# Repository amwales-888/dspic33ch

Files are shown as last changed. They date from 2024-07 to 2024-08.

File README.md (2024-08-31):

# dspic33ch

Simple development board for 3.3v 80pin TQFP dspic33ch.

- 3.3v LDO powered from 5V USB.
- UART connectivity to USB via ch340 optionally connected using jumpers B1-B2.
- programming interface header.
- With exception of CLKI (B0) and MCLR all other pins are broken out to headers.
- 2 LEDS optionally connected to pins A0-A1 using jumpers.
- 2 Buttons optionally connected to pins A2-A3 using jumpers.

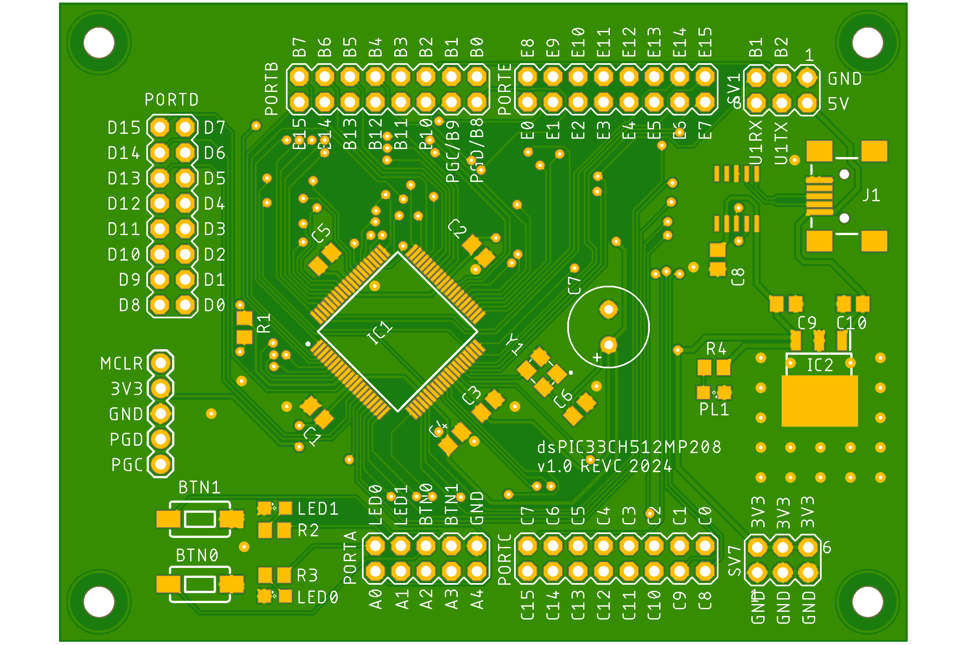
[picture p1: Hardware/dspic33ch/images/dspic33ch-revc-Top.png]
Board Top

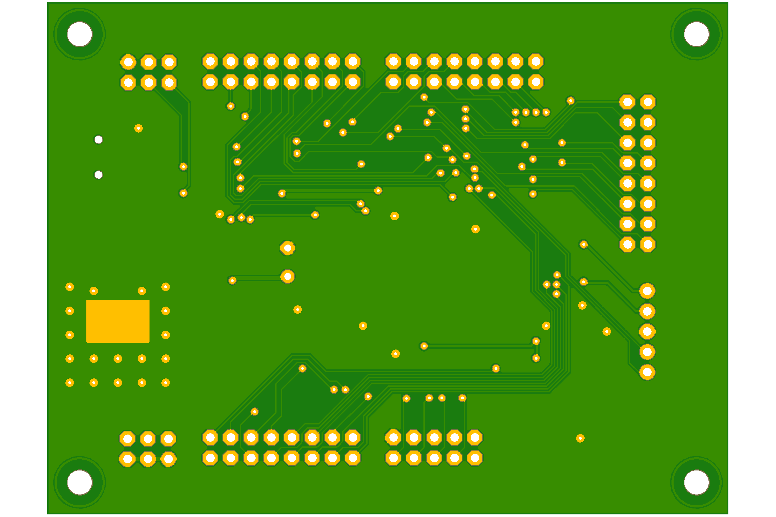
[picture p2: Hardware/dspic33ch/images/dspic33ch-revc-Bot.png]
Board Bottom


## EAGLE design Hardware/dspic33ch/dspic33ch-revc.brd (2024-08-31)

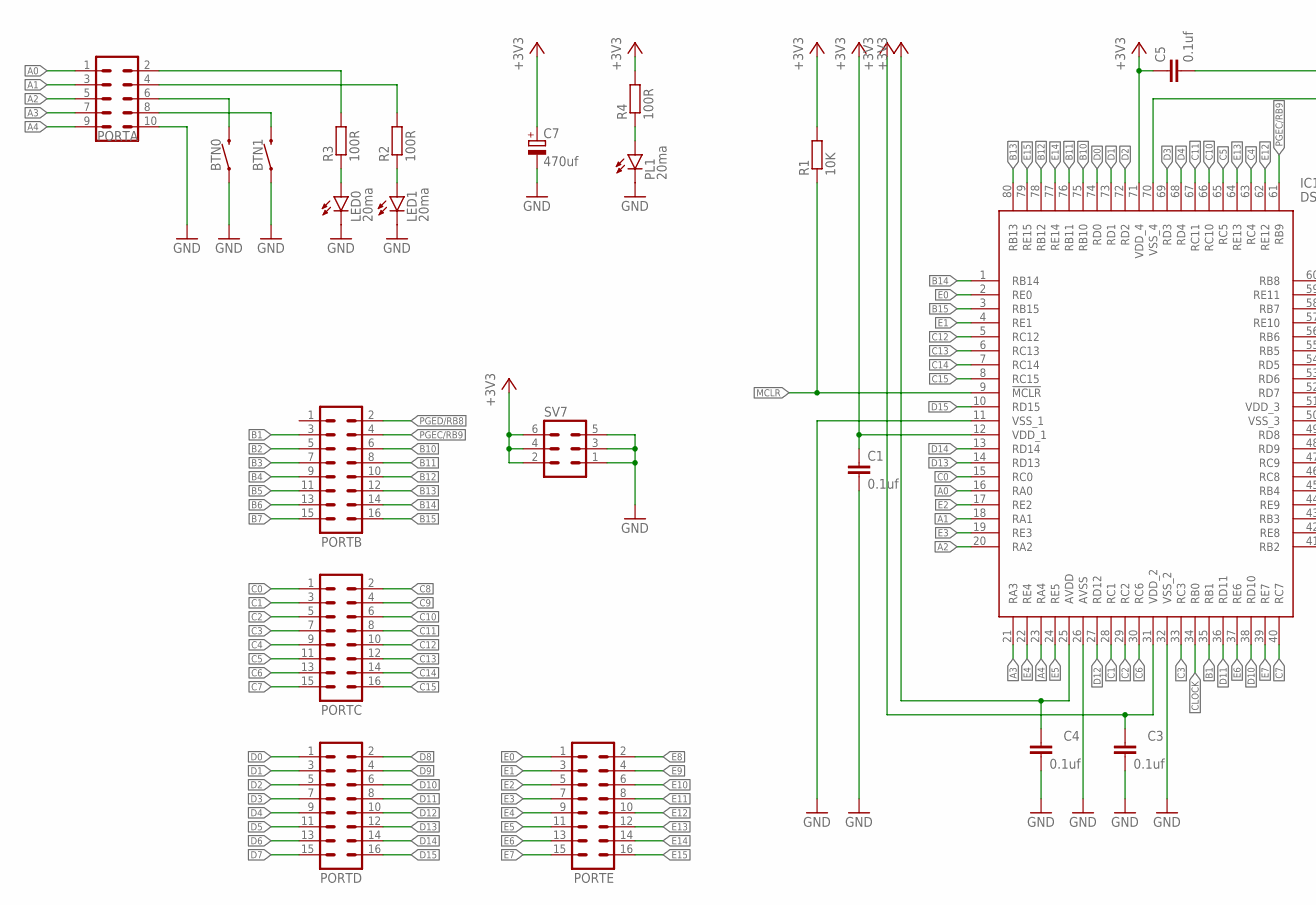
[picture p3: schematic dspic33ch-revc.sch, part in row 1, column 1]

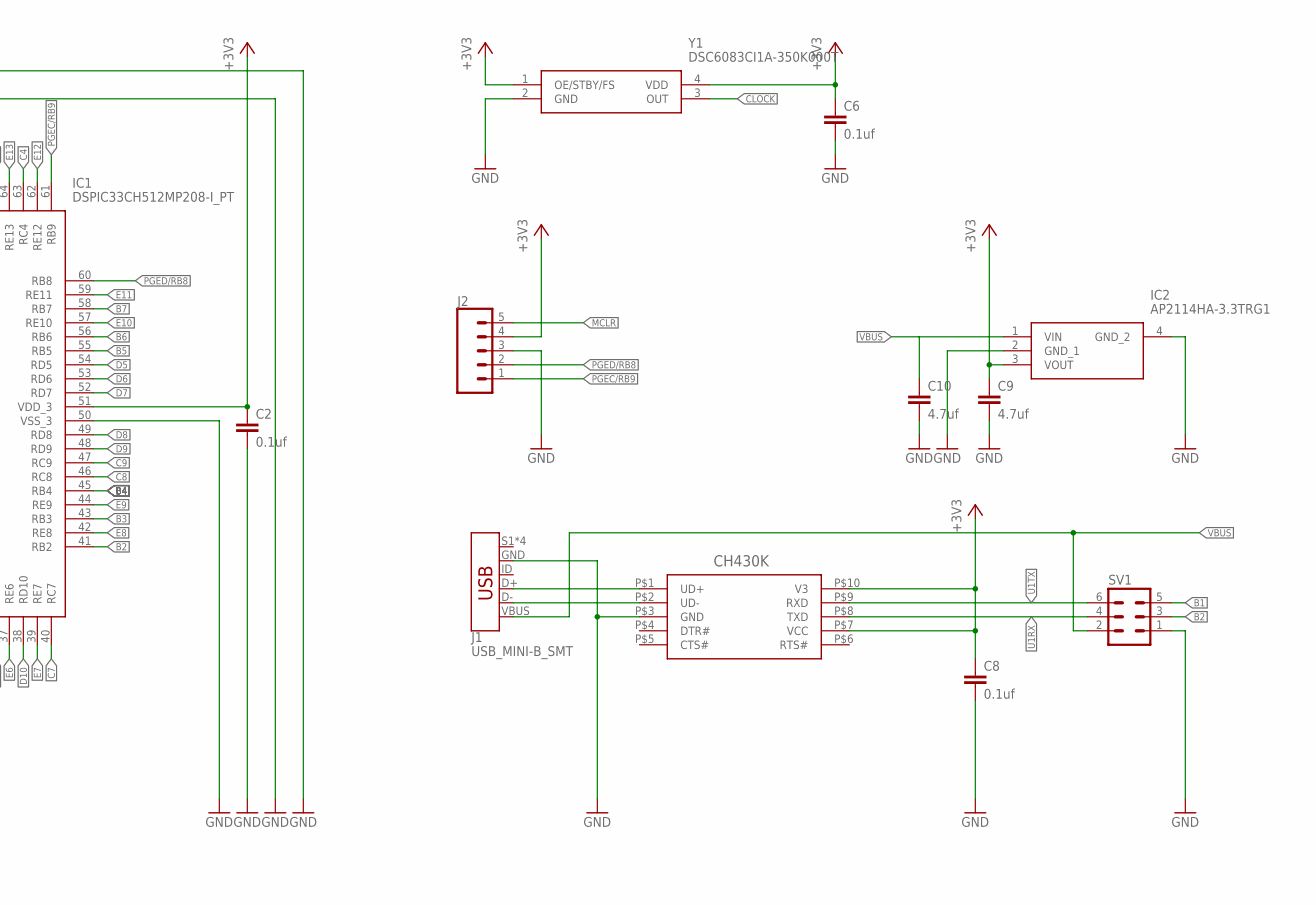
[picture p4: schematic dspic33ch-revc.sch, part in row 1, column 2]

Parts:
BTN0, BTN1: MOMENTARY-SWITCH-SPST-SMD-6.0X3.5MM; TACTILE_SWITCH_SMD_6.0X3.5MM
C1, C2, C3, C4, C5, C6, C8: 0.1uf; C0805
C7: 470uf; E3,5-8
C9, C10: 4.7uf; C0805
IC1: DSPIC33CH512MP208-I_PT; QFP50P1400X1400X120-80N
IC2: AP2114HA-3.3TRG1; SOT230P700X180-4N
J1: USB_MINI-B_SMT; USB-MINIB
J2: CONN_05; 1X05
LED0, LED1: 20ma; SML0805
PL1: 20ma; SML0805
PORTA: MA05-2
PORTB: MA08-2
PORTC: MA08-2
PORTD: MA08-2
PORTE: MA08-2
R1: 10K; R0805
R2, R3, R4: 100R; R0805
SV1, SV7: MA03-2
U$1: CH430K; ESSOP-10
Y1: DSC6083CI1A-350K000T; DSC6083CI1A350K000T

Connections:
+3V3: C1.1, C2.1, C3.1, C4.1, C5.1, C6.1, C7.+, C8.1, C9.1, IC1.12 (VDD_1), IC1.25 (AVDD), IC1.31 (VDD_2), IC1.51 (VDD_3), IC1.71 (VDD_4), IC2.3 (VOUT), J2.4, R1.2, R4.2, SV7.2, SV7.4, SV7.6, U$1.P$7 (VCC), U$1.P$10 (V3), Y1.1 (OE/STBY/FS), Y1.4 (VDD)
A0: IC1.16 (RA0), PORTA.1
A1: IC1.18 (RA1), PORTA.3
A2: IC1.20 (RA2), PORTA.5
A3: IC1.21 (RA3), PORTA.7
A4: IC1.23 (RA4), PORTA.9
B1: IC1.35 (RB1), PORTB.3, SV1.5
B2: IC1.41 (RB2), PORTB.5, SV1.3
B3: IC1.43 (RB3), PORTB.7
B4: IC1.45 (RB4), PORTB.9
B5: IC1.55 (RB5), PORTB.11
B6: IC1.56 (RB6), PORTB.13
B7: IC1.58 (RB7), PORTB.15
B10: IC1.75 (RB10), PORTB.6
B11: IC1.76 (RB11), PORTB.8
B12: IC1.78 (RB12), PORTB.10
B13: IC1.80 (RB13), PORTB.12
B14: IC1.1 (RB14), PORTB.14
B15: IC1.3 (RB15), PORTB.16
C0: IC1.15 (RC0), PORTC.1
C1: IC1.28 (RC1), PORTC.3
C2: IC1.29 (RC2), PORTC.5
C3: IC1.33 (RC3), PORTC.7
C4: IC1.63 (RC4), PORTC.9
C5: IC1.65 (RC5), PORTC.11
C6: IC1.30 (RC6), PORTC.13
C7: IC1.40 (RC7), PORTC.15
C8: IC1.46 (RC8), PORTC.2
C9: IC1.47 (RC9), PORTC.4
C10: IC1.66 (RC10), PORTC.6
C11: IC1.67 (RC11), PORTC.8
C12: IC1.5 (RC12), PORTC.10
C13: IC1.6 (RC13), PORTC.12
C14: IC1.7 (RC14), PORTC.14
C15: IC1.8 (RC15), PORTC.16
CLOCK: IC1.34 (RB0), Y1.3 (OUT)
D0: IC1.74 (RD0), PORTD.1
D1: IC1.73 (RD1), PORTD.3
D2: IC1.72 (RD2), PORTD.5
D3: IC1.69 (RD3), PORTD.7
D4: IC1.68 (RD4), PORTD.9
D5: IC1.54 (RD5), PORTD.11
D6: IC1.53 (RD6), PORTD.13
D7: IC1.52 (RD7), PORTD.15
D8: IC1.49 (RD8), PORTD.2
D9: IC1.48 (RD9), PORTD.4
D10: IC1.38 (RD10), PORTD.6
D11: IC1.36 (RD11), PORTD.8
D12: IC1.27 (RD12), PORTD.10
D13: IC1.14 (RD13), PORTD.12
D14: IC1.13 (RD14), PORTD.14
D15: IC1.10 (RD15), PORTD.16
E0: IC1.2 (RE0), PORTE.1
E1: IC1.4 (RE1), PORTE.3
E2: IC1.17 (RE2), PORTE.5
E3: IC1.19 (RE3), PORTE.7
E4: IC1.22 (RE4), PORTE.9
E5: IC1.24 (RE5), PORTE.11
E6: IC1.37 (RE6), PORTE.13
E7: IC1.39 (RE7), PORTE.15
E8: IC1.42 (RE8), PORTE.2
E9: IC1.44 (RE9), PORTE.4
E10: IC1.57 (RE10), PORTE.6
E11: IC1.59 (RE11), PORTE.8
E12: IC1.62 (RE12), PORTE.10
E13: IC1.64 (RE13), PORTE.12
E14: IC1.77 (RE14), PORTE.14
E15: IC1.79 (RE15), PORTE.16
GND: BTN0.1, BTN1.1, C1.2, C2.2, C3.2, C4.2, C5.2, C6.2, C7.-, C8.2, C9.2, C10.2, IC1.11 (VSS_1), IC1.26 (AVSS), IC1.32 (VSS_2), IC1.50 (VSS_3), IC1.70 (VSS_4), IC2.2 (GND_1), IC2.4 (GND_2), J1.GND, J2.3, LED0.C, LED1.C, PL1.C, PORTA.10, SV1.1, SV7.1, SV7.3, SV7.5, U$1.P$3 (GND), Y1.2 (GND)
MCLR: IC1.9 (!MCLR), J2.5, R1.1
unnamed: LED1.A, R2.1
unnamed: PORTA.2, R3.2
unnamed: PORTA.4, R2.2
unnamed: LED0.A, R3.1
unnamed: BTN0.2, PORTA.6
unnamed: PL1.A, R4.1
unnamed: BTN1.2, PORTA.8
PGEC/RB9: IC1.61 (RB9), J2.1, PORTB.4
PGED/RB8: IC1.60 (RB8), J2.2, PORTB.2
U1RX: SV1.4, U$1.P$8 (TXD)
U1TX: SV1.6, U$1.P$9 (RXD)
USB_N: J1.D-, U$1.P$2 (UD-)
USB_P: J1.D+, U$1.P$1 (UD+)
VBUS: C10.1, IC2.1 (VIN), J1.VBUS, SV1.2

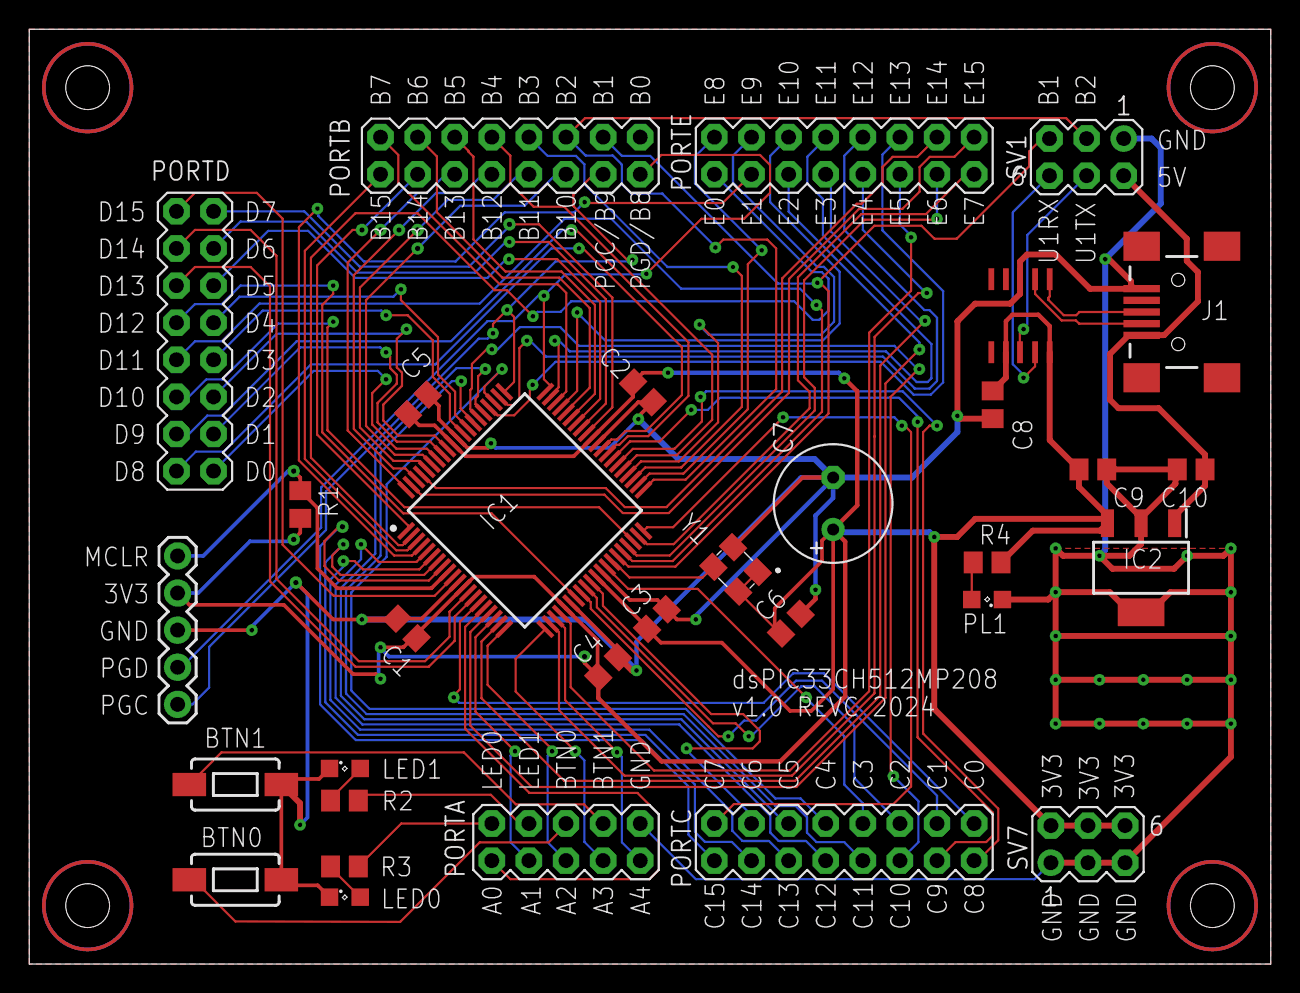
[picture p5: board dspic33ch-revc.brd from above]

Board: 2 copper layers, 85.0 x 64.0 mm, 32 parts (0 on the bottom side), 84 nets.

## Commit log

2024-07-28 Initial Checkin
    [dspic33ch-revb.brd, dspic33ch-revb.sch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]
2024-08-04 Fix to ch340 so it operates at 3v3 instead of 5v
    [dspic33ch-revc.brd, dspic33ch-revc.sch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]
2024-08-04 Silkscreen incorrect version
    [dspic33ch-revc.brd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]
2024-08-31 revc final gerbers produced
    [dspic33ch-revc.brd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]

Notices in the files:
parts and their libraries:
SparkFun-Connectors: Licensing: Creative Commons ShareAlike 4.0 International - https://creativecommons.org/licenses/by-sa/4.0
